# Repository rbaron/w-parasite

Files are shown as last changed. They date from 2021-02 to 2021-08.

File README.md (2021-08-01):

🚨 **This project is no longer recommended!** 🚨. Please check out the evolution of it - the [b-parasite](https://github.com/rbaron/b-parasite).

# w-parasite

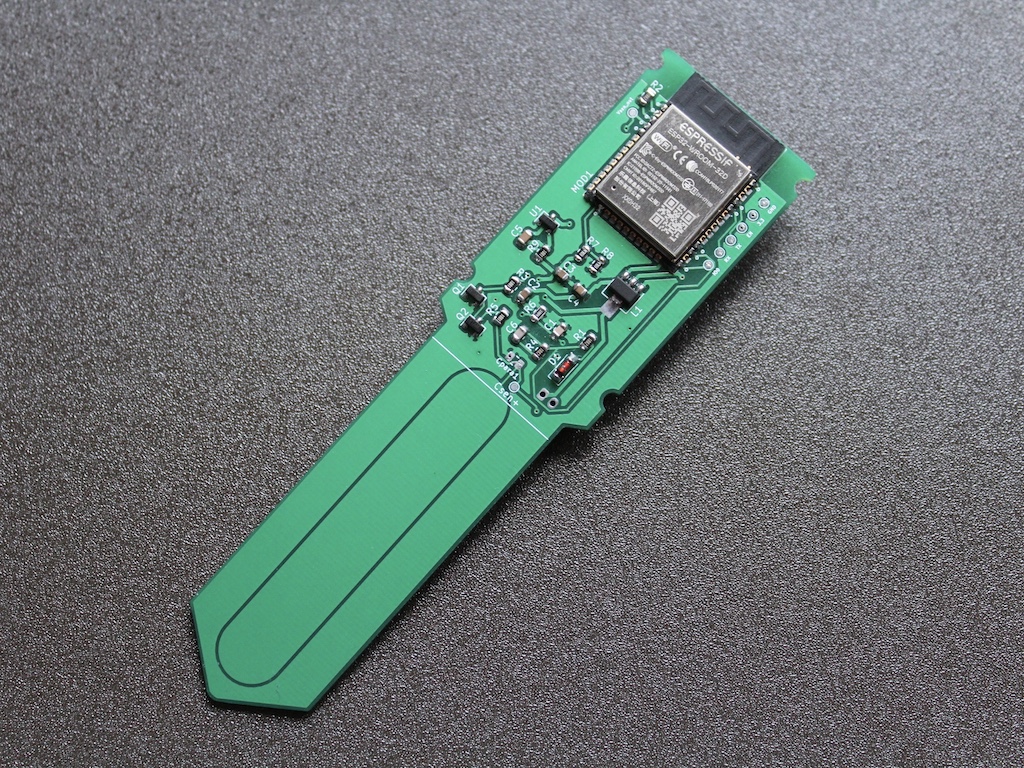
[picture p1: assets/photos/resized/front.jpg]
Front

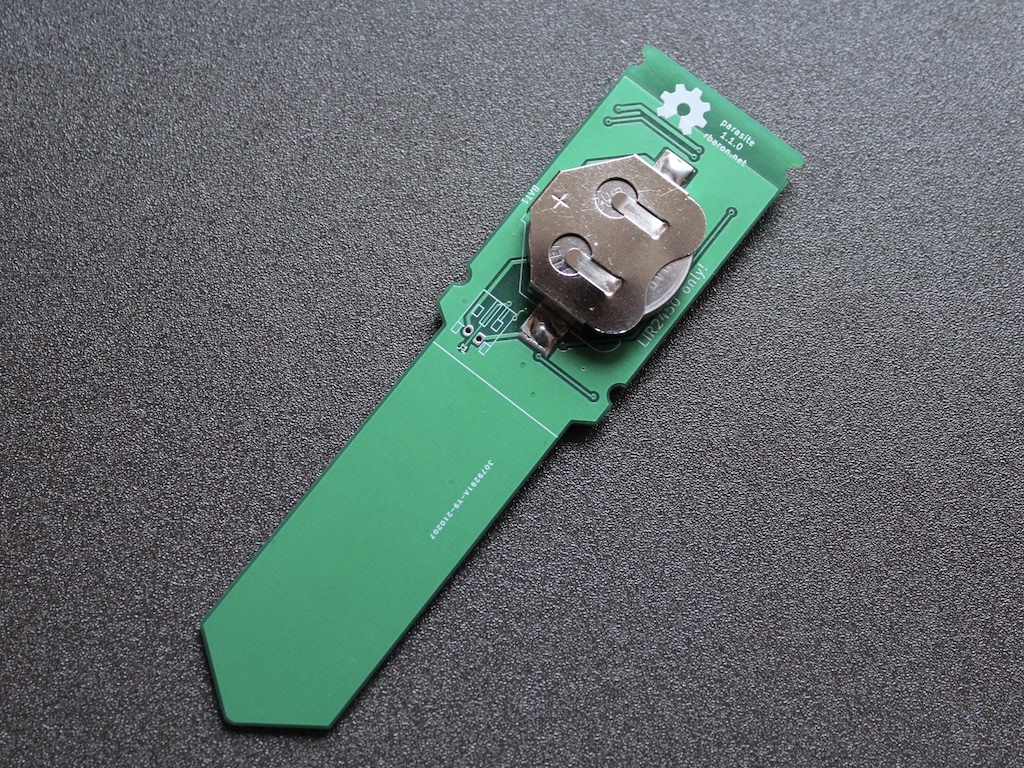
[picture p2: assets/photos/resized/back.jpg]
Back


w-parasite is an open source, WiFi-enabled soil moisture sensor for house plants.

This repo contains all the hardware design files (schematic, printed circuit board layout) and code for customizing and making your own w-parasite.

# How It Works
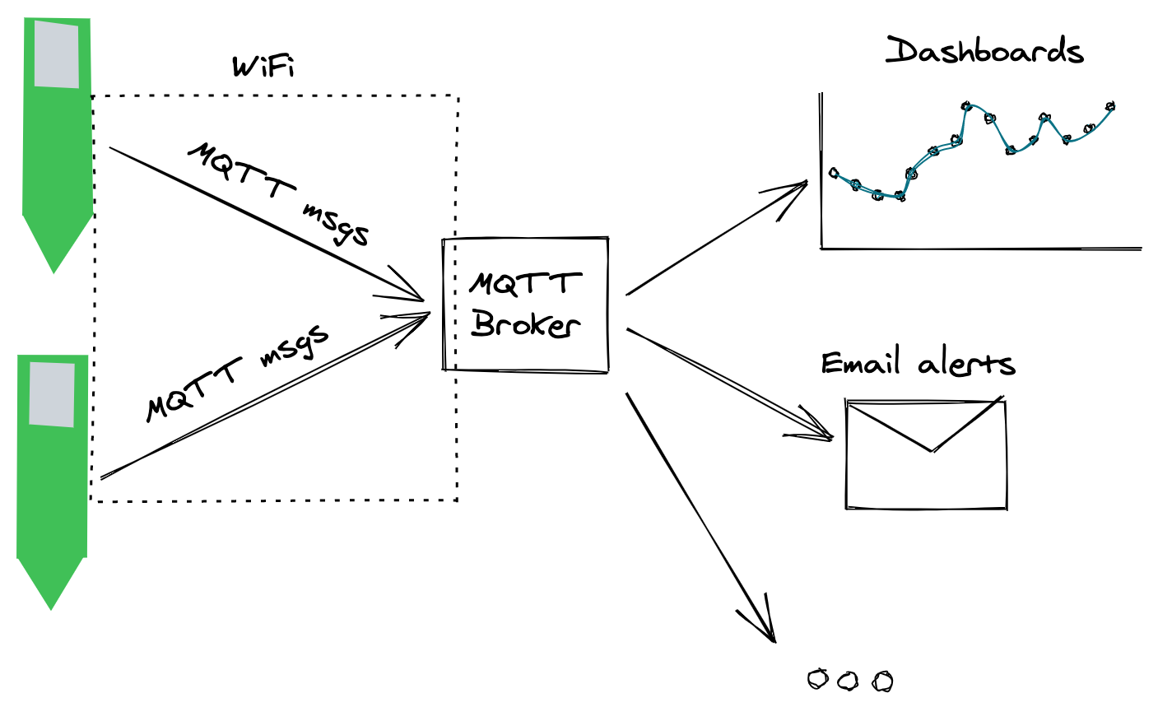
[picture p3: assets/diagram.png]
Diagram


w-parasite works by reading the soil moisture level and transmitting that information via MQTT messages via WiFi. To save battery, the board sleeps most of the time, and only wakes up every few minutes, at which point it takes a reading and ships it to the MQTT broker.

An [ESP32](https://www.espressif.com/en/products/socs/esp32) sits at the heart of the board, and is responsible for managing the sensors and connecting to WiFi.

The board can be powered with LiPo/Li-Ion batteries. There is a battery clip for rechargeable LIR2450 batteries, as well as a possibility for soldering a JST connector for beefier LiPo/Li-Ion batteries.

# Moisture Sensor
To measure the soil moisture, two PCB traces act like a disguised capacitor. These are the two large copper traces on the bottom of the board, on the part that goes into the soil. The capacitance between these two traces vary according to the amount of water around them, and we exploit that phenomenom to infer the soil moisture.

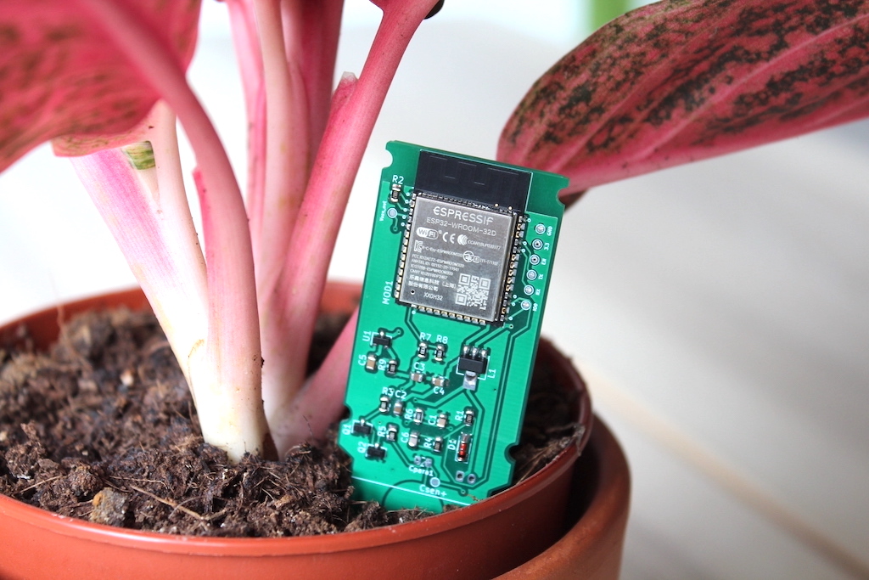
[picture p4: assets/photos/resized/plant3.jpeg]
A picture of the sensor in the ground


[This great post](https://wemakethings.net/2012/09/26/capacitance_measurement/) on wemakethings goes into detail about the inner workings of capacitive soil moisture sensors. I also expanded a little bit on the topic it in [here](https://twitter.com/rbaron_/status/1367182806368071685).

# Repo Organization
* [`code/`](./code/): Software. It's an [arduino-esp32](https://github.com/espressif/arduino-esp32/) [PlatformIO](https://platformio.org/) project;
* [`kicad/`](./kicad/): Hardware. It's a [KiCad](https://kicad.org/) project with the electronics schematic, PCB layout & fabrication files;

# Battery Life
To estimate the battery life and discuss our choices, we can agree on a few premisses:
1. Soil moisture doesn't change abruptly (except when watered). It is okay to wait several minutes between readings.
2. Most of the time, the sensor will be in a low power mode ("deep sleep"), in which its CPU is not active and it's not connected to WiFi. The current consumption in this state can be brought to around 15uA (10uA for the ESP32 and around 6uA for the voltage regulator - LDO);
3. When the sensor is active, its current consumption is orders of magniture higher. WiFi and ESP32 are not usually a good choice for low power devices, but since we can get away with such long periods of deep sleep, we might just barely get away with it. When active, w-parasite can consume peaks of over 200mA. It is paramount that we keep the active time short - cutting it down from 2 seconds to 1 second essentially doubles the battery life.

I have experimented with two main types of battery:
- LIR2450 Li-Ion coin cells. They are super compact (as in the photo above). With around 120mAh, they can only source short peaks of 200mA, which is below what the ESP32 expects. Using them poses a challenge on capacity and current, and that's why we like it so much;
- LiPo/Li-Ion cells. They are generally a lot bigger but usually pack up to 3000mAh. They take a lot of space but comfortably powers w-parasite for well over a year;

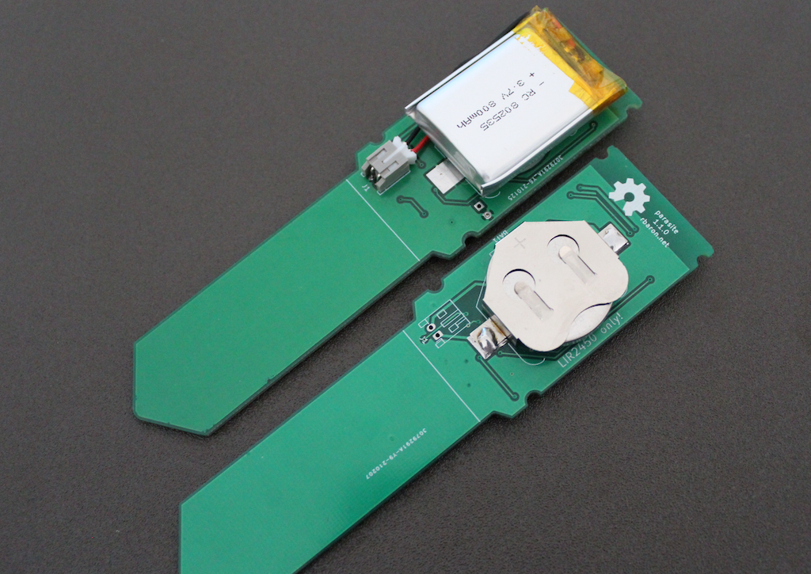
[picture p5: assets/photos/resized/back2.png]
Back with two w-parasites with different batteries


I put together [this spreadsheet](https://docs.google.com/spreadsheets/d/1Lt3Obveo7YzpxWigAVeM2rHjrGED6iG8pZ1Y3q1cldg/edit#gid=0) to estimate battery life. Here are some example scenarios:
- LIR2450 cell (120mAh), transmitting every 30 minutes: around 80-90 days.
- 1200mAh LiPo, transmitting every 10 minutes: over a year;
- 18650 Li-Ion (e.g.: 2700mAh), transmitting every 5 minutes: over a year;

# Possible Improvements
Ideas for improvements go in the direction of battery saving by shaving off precious milliseconds during the active cycle:

* Use a static IP address, BSSID and static dns servers. This has the downside of being less plug-and-play, so we need to investigate if the savings in connection time are worth it;
* Reduce boot time. We can configure esp-idf to suppress boot logging. This will probably require re-compiling the SDK ourselves, as Arduino/PlatformIO uses a prebuilt binary. See [this Github doc](https://github.com/espressif/arduino-esp32/blob/master/docs/esp-idf_component.md). [This Reddit thread](https://www.reddit.com/r/esp32/comments/fnj51a/a_guide_to_improving_esp32_boot_speed/) also has valuable info. Major savings seem to come from:
  * Pulling GPIO15 down on reset. It disables UART output;
  * Set BOOTLOADER_LOG_LEVEL to NONE/ERRORS;
  * ESPTOOL_FLASHMODE: QIO if possible;
  * SPIRAM_MEMTEST: disable RAM test;
* Experiment with a 3.0V LDO (such as the HT7330). The ESP32 should be able to run with 3.0V (instead of the nominal 3.3V we're using here, which has a 0.9V dropout voltage, so we can only power it with at least 3.39V). This would make better use of the LIR2450 cell. From the [LIR2450 discharge curve](https://devzone.nordicsemi.com/cfs-file/__key/communityserver-discussions-components-files/4/1307.3.png), I don't think the gains are massive, but we could probably squeeze 10%-ish more out of the LIR2450;
* Tigther MQTT messages. We currently send out multiple MQTT messages. This makes it easy to work with on the other end, but we can probably do better to bring the runtime down;

# Why not Bluetooth Low Energy (BLE)?
Excellent question! With BLE, we can work with much lower currents, and we can power the board with even cheaper batteries like the ubiquitous CR2032. SoCs like the [nRF5](https://www.nordicsemi.com/Products/Low-power-short-range-wireless) family from Nordic are much better suited for ultra low power applications. They idle at less than 1uA and can transmit with ~5mA (compare with 100-200mA for the ESP32 + WiFi)! I believe they are a better fit for battery-powered, intermittent sensors like this one. Moreover, ESP32, _specially_ with WiFi is notoriously power hungry. Even if we implement all the tricks in the book, we won't likely match the power efficiency of BLE-only chips.

With all that out of the way, if we power this with a beefier LiPo/Li-Ion battery, we can hopefuly already run for over a year on a single charge, with the added advantage of having a simpler architechure and more friendly - the sensor talks directly to your MQTT broker. Additionally, BLE devices usually have a much lower range and often require bridges for integrating with the rest of our system.

# News & Updates
For the freshest w-parasite updates, follow [@rbaron_](https://twitter.com/rbaron_).

# License
The hardware and associated design files are released under the [Creative Commons CC BY-SA 4.0 license](https://creativecommons.org/licenses/by-sa/4.0/).
The code is released under the [MIT license](https://opensource.org/licenses/MIT).

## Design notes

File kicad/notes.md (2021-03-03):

# LIR2450 Coin Battery
- Capacity ~130 mAh
- Charging current ~45mA (0.5C)

Available chargers are suspiciously cheap and rare.

## ICS for charging
- [LTC4071](https://www.analog.com/media/en/technical-documentation/data-sheets/LTC4071.pdf)
- [MCP73831/2](https://cdn-reichelt.de/documents/datenblatt/A200/MCP73831-2_ENG_TDS.pdf)
  Seems easier to use, but does not offer undervoltage protection.
- [MCP73831]

## ICS for protection against undercharge/overcurrent
- [DW01A](https://lcsc.com/product-detail/Battery-Protection-ICs_PUOLOP-DW01A_C351410.html)
  This one I found built-in into protected batteries, but it requires two external MOSFETS.
- [XB6566H](https://datasheet.lcsc.com/szlcsc/1810010232_XySemi-XB6566H0_C190847.pdf)
  Used on the esp32 coin project. Requires minimal external components.

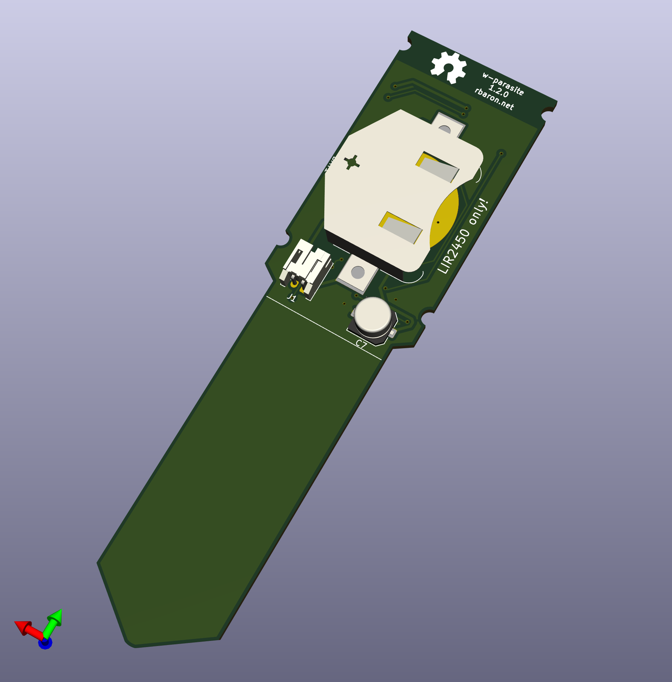
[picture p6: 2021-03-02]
assets/3dback.png

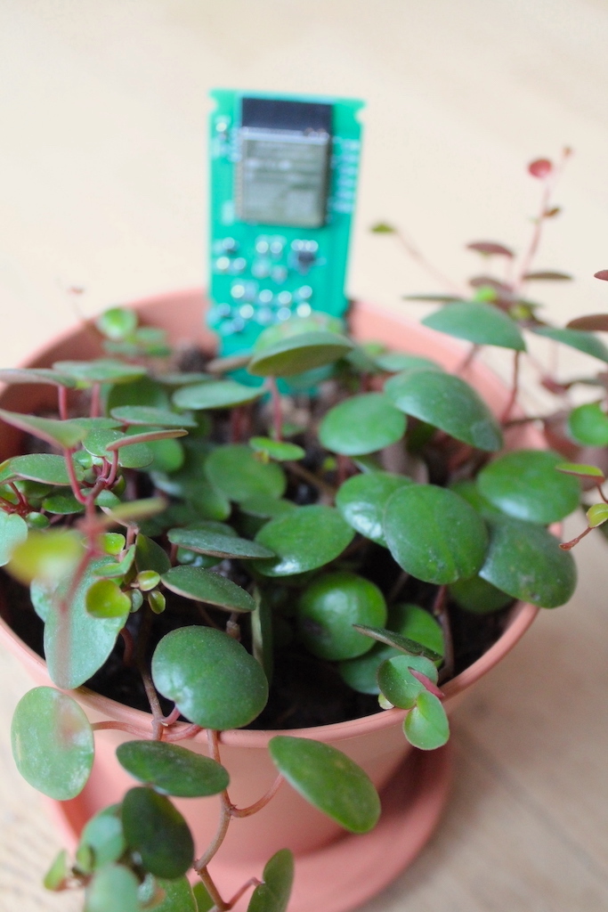
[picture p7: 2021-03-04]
assets/photos/resized/plant1.jpg

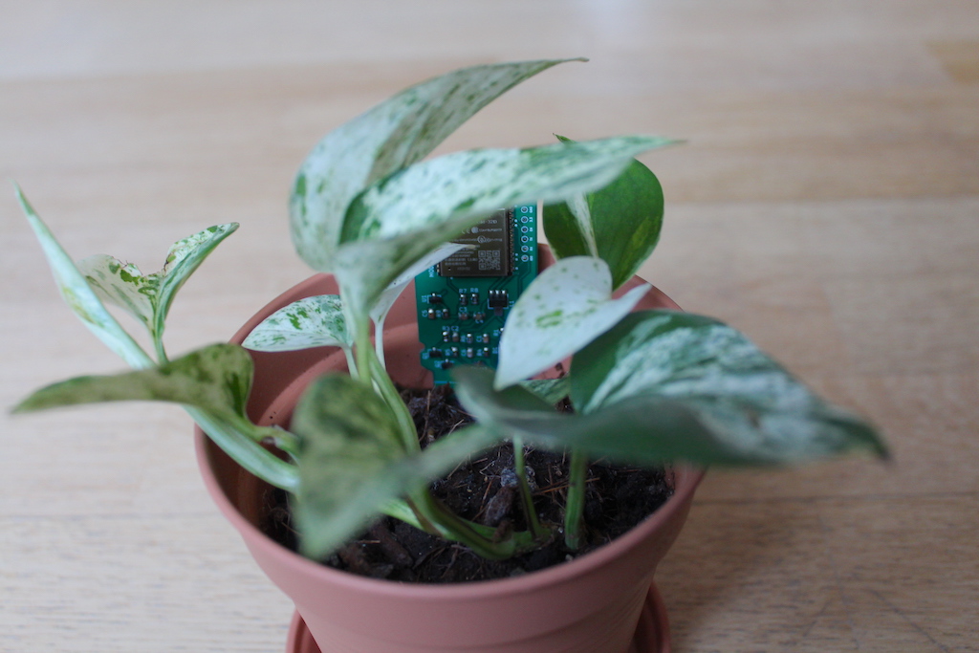
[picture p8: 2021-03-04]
assets/photos/resized/plant2.jpg

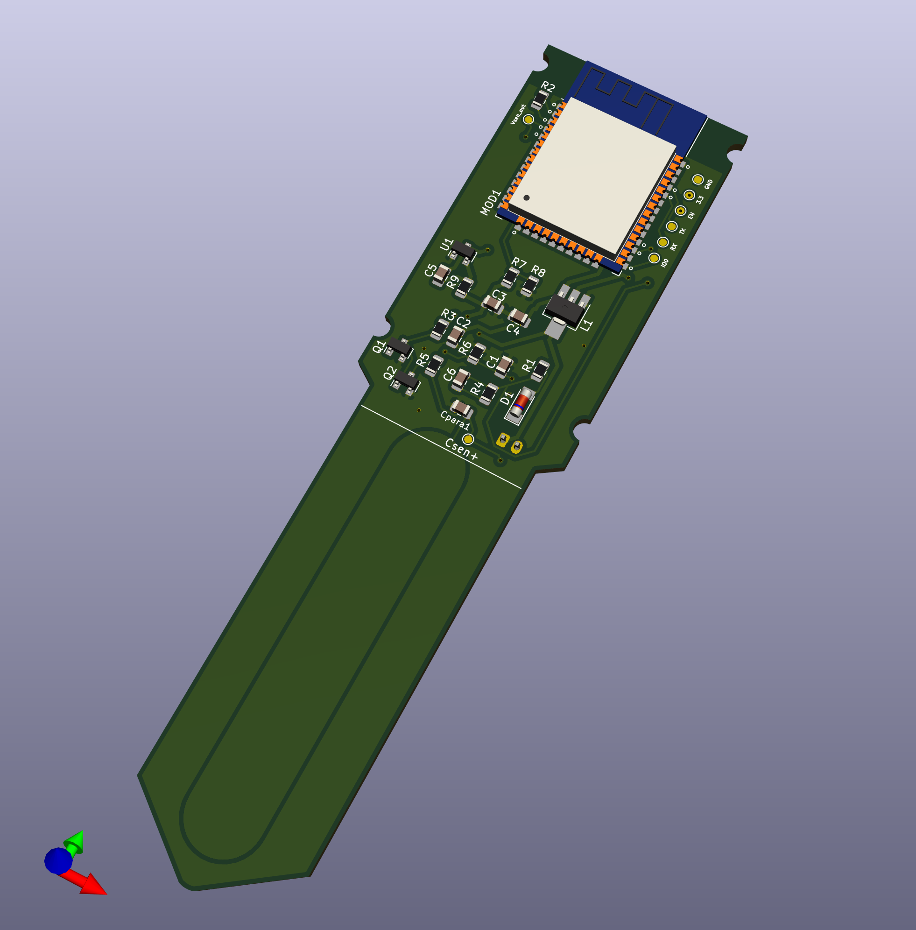
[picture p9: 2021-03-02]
assets/3dfront.png

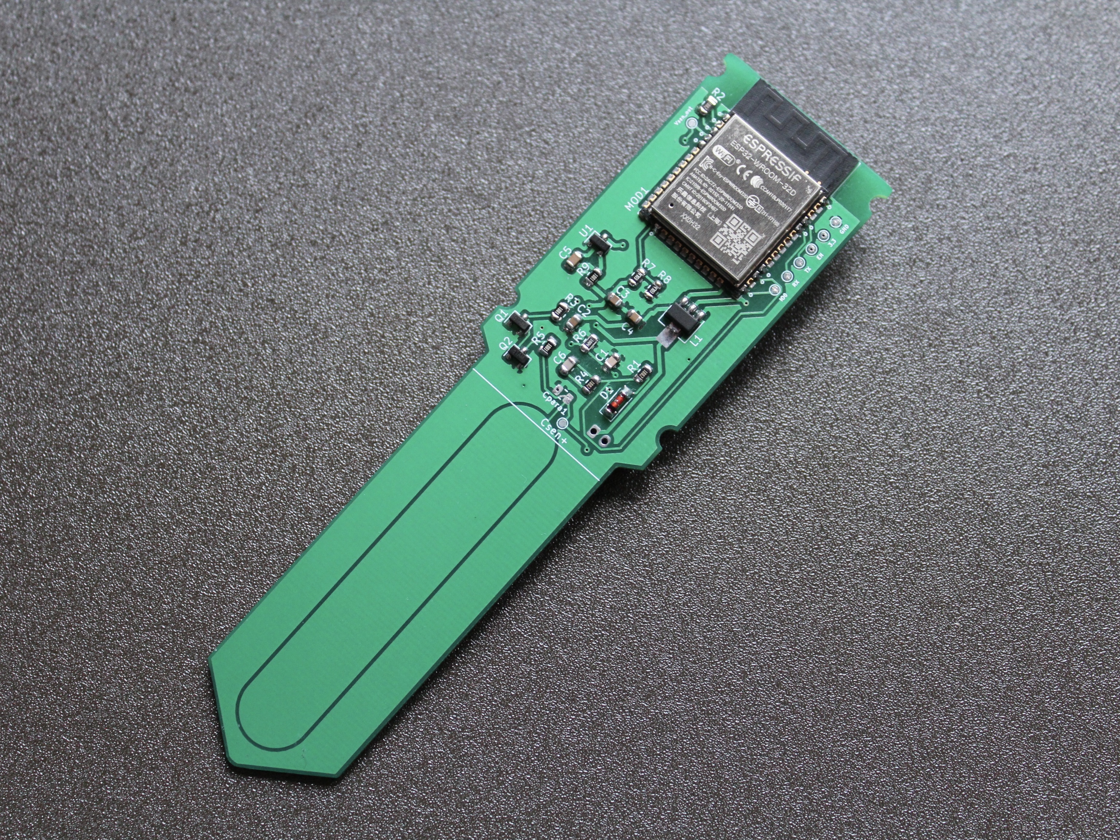
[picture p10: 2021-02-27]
assets/photos/original/front.jpg

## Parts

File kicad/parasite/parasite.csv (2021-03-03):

Id | Designator | Package | Quantity | Designation | Supplier and ref
1 | G*** | OSHW-logo_silkscreen-back_8mm | 1 | OSHW-logo_silkscreen-back_8mm
2 | BAT1 | BatteryHolder_Keystone_3008_1x2450 | 1 | BS-7
3 | R8,R7 | R_0805_2012Metric | 2 | 470k
4 | TP9 | TestPoint_Pad_D1.0mm | 1 | GND
5 | TP8 | TestPoint_Pad_D1.0mm | 1 | 3.3
6 | Q2,Q1 | SOT-23 | 2 | MMBT3904
7 | Cpara1 | C_0805_2012Metric | 1 | 5p
8 | C1 | C_0805_2012Metric | 1 | 1n
9 | C2,C3,C4 | C_0805_2012Metric | 3 | 10u
10 | D1 | D_MiniMELF | 1 | LL4148
11 | J1 | JST_PH_S2B-PH-K_1x02_P2.00mm_Horizontal | 1 | Conn_01x02_Female
12 | L1 | SOT-89-3_Handsoldering | 1 | HT7333-A
13 | MOD1 | ESP32-WROOM-32 | 1 | ESP32-WROOM-32
14 | R1,R2,R4 | R_0805_2012Metric | 3 | 10k
15 | R3,R5,R9 | R_0805_2012Metric | 3 | 1k
16 | R6 | R_0805_2012Metric | 1 | 1M
17 | TP1 | TestPoint_Pad_D1.0mm | 1 | IO0
18 | TP2 | TestPoint_Pad_D1.0mm | 1 | EN
19 | TP3 | TestPoint_Pad_D1.0mm | 1 | Csen+
20 | TP4 | TestPoint_Pad_D1.0mm | 1 | Vsen_out
21 | TP5 | TestPoint_Pad_D1.0mm | 1 | TX
22 | TP6 | TestPoint_Pad_D1.0mm | 1 | RX
23 | C6 | C_0805_2012Metric | 1 | 100p
24 | C5 | C_0805_2012Metric | 1 | 0.1u
25 | U1 | SOT-23 | 1 | XB3303A

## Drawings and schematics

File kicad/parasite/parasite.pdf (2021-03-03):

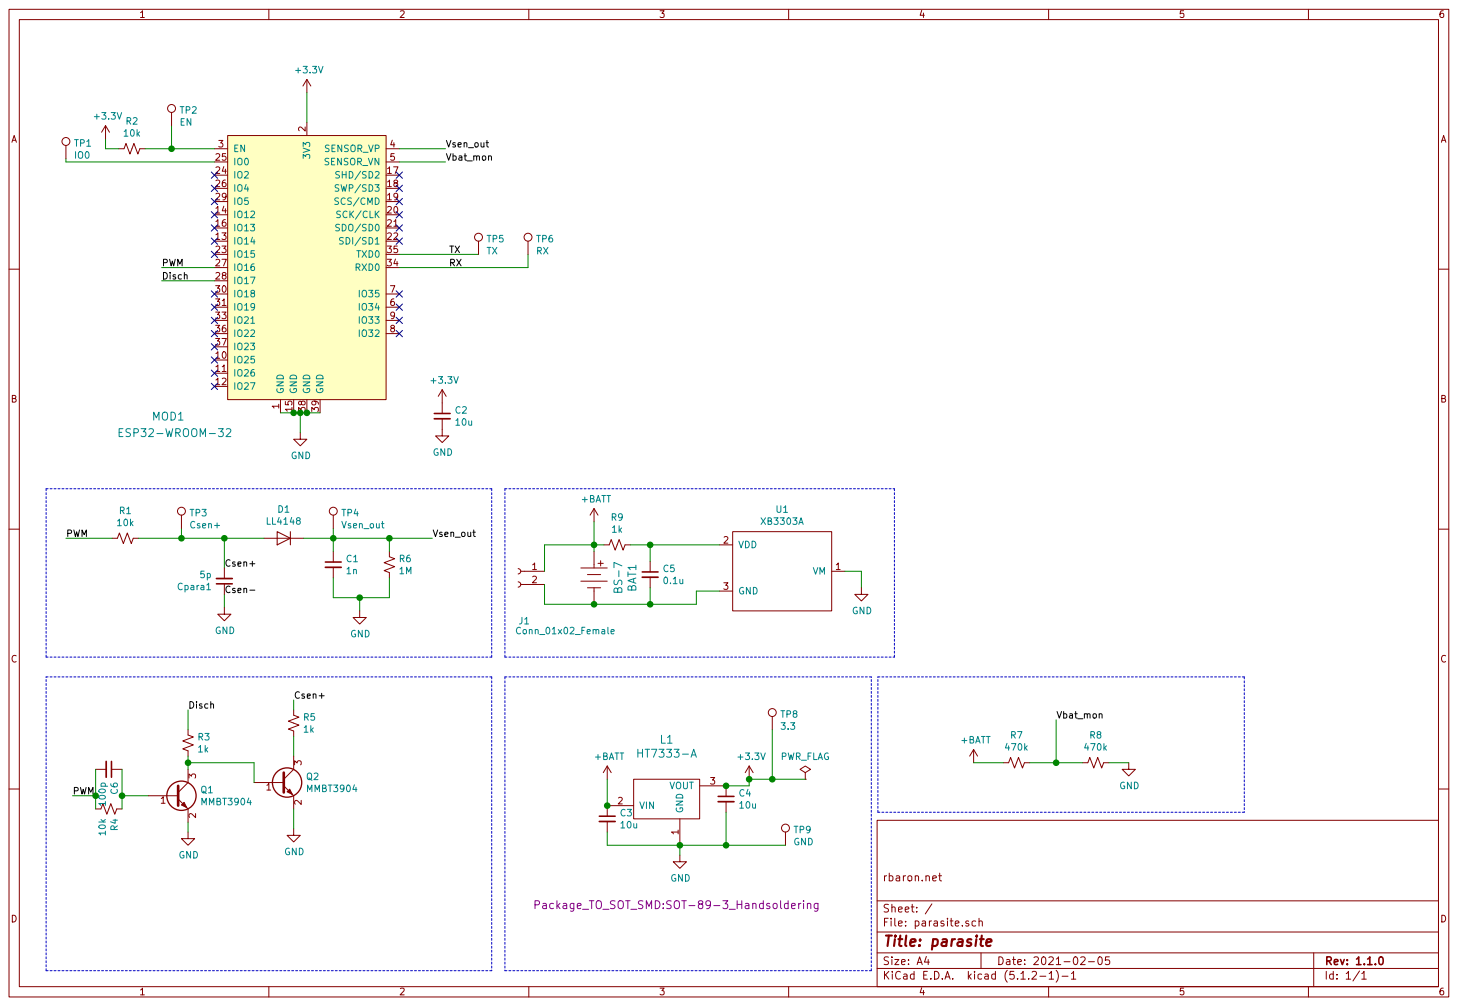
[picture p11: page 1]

File: parasite.sch Sheet: / rbaron.net GND

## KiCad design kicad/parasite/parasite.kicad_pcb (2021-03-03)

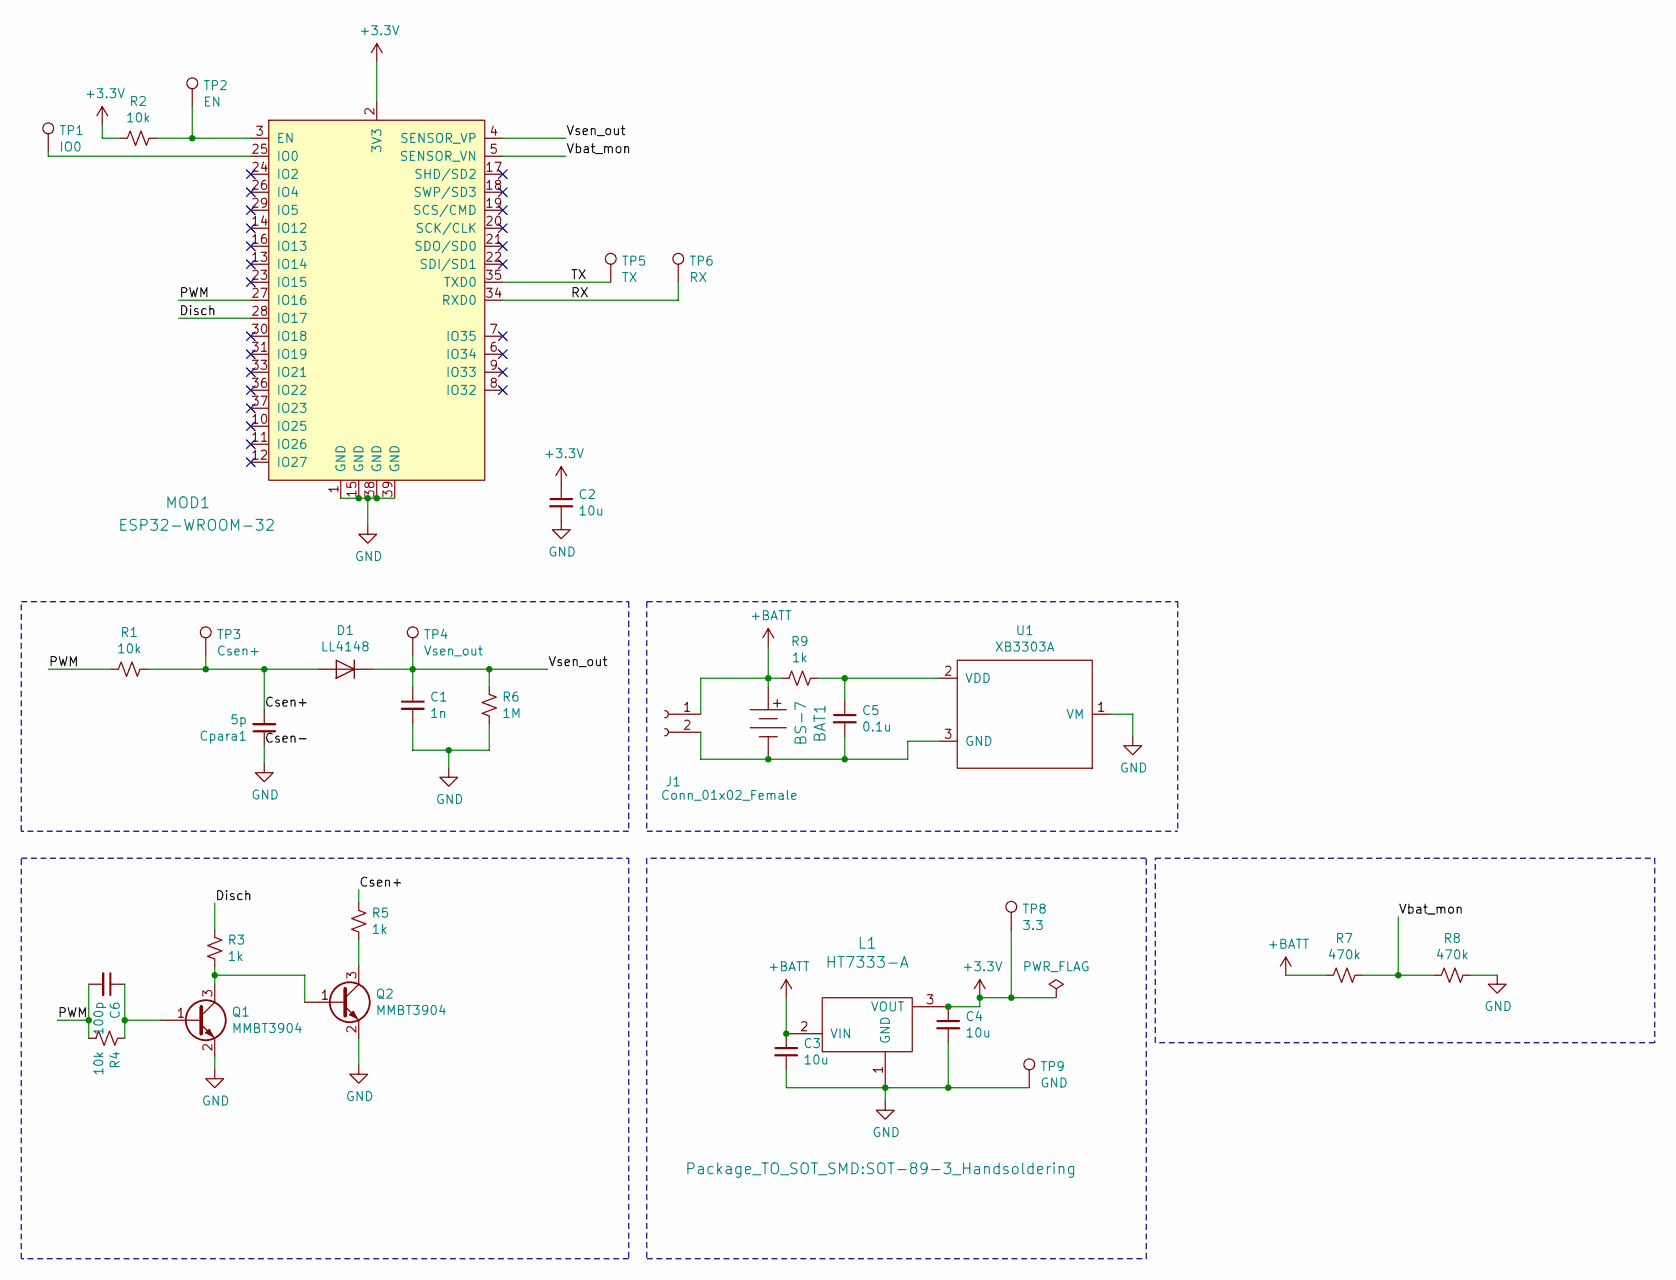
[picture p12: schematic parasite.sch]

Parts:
BAT1: BS-7; BatteryHolder_Keystone_3008_1x2450; MPN BS-7; Digi-Key_PN BS-7-ND
C1: 1n; C_0805_2012Metric
C2, C3, C4: 10u; C_0805_2012Metric
C5: 0.1u; C_0805_2012Metric
C6: 100p; C_0805_2012Metric
Cpara1: 5p; C_0805_2012Metric
D1: LL4148; D_MiniMELF
J1: Conn_01x02_Female; JST_PH_S2B-PH-K_1x02_P2.00mm_Horizontal
L1: HT7333-A; SOT-89-3_Handsoldering
MOD1: ESP32-WROOM-32; MPN ESP32-WROOM-32; Digi-Key_PN 1904-1010-1-ND
Q1, Q2: MMBT3904; SOT-23
R1, R2, R4: 10k; R_0805_2012Metric
R3, R5, R9: 1k; R_0805_2012Metric
R6: 1M; R_0805_2012Metric
R7, R8: 470k; R_0805_2012Metric
TP1: IO0; TestPoint_Pad_D1.0mm
TP2: EN; TestPoint_Pad_D1.0mm
TP3: Csen+; TestPoint_Pad_D1.0mm
TP4: Vsen_out; TestPoint_Pad_D1.0mm
TP5: TX; TestPoint_Pad_D1.0mm
TP6: RX; TestPoint_Pad_D1.0mm
TP8: 3.3; TestPoint_Pad_D1.0mm
TP9: GND; TestPoint_Pad_D1.0mm
U1: XB3303A; SOT-23

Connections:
+3V3: C2.1, C4.1, L1.3 (VOUT), MOD1.2 (3V3), R2.1, TP8.1
+BATT: BAT1.Pos, C3.1, J1.1, L1.2 (VIN), R7.1, R9.1
/Csen+: Cpara1.2, D1.2 (A), R1.2, R5.1, TP3.1
/Disch: MOD1.28 (IO17), R3.1
/PWM: C6.2, MOD1.27 (IO16), R1.1, R4.2
/RX: MOD1.34 (RXD0), TP6.1
/TX: MOD1.35 (TXD0), TP5.1
/Vbat_mon: MOD1.5 (SENSOR_VN), R7.2, R8.1
/Vsen_out: C1.1, D1.1 (K), MOD1.4 (SENSOR_VP), R6.1, TP4.1
GND: C1.2, C2.2, C3.2, C4.2, Cpara1.1, L1.1 (GND), MOD1.1 (GND), MOD1.15 (GND), MOD1.38 (GND), MOD1.39 (GND), Q1.2 (E), Q2.2 (E), R6.2, R8.2, TP9.1, U1.1 (VM)
unnamed: BAT1.Neg, C5.2, J1.2, U1.3 (GND)
unnamed: C5.1, R9.2, U1.2 (VDD)
unnamed: C6.1, Q1.1 (B), R4.1
unnamed: MOD1.3 (EN), R2.2, TP2.1
unnamed: MOD1.25 (IO0), TP1.1
unnamed: Q1.3 (C), Q2.1 (B), R3.2
unnamed: Q2.3 (C), R5.2

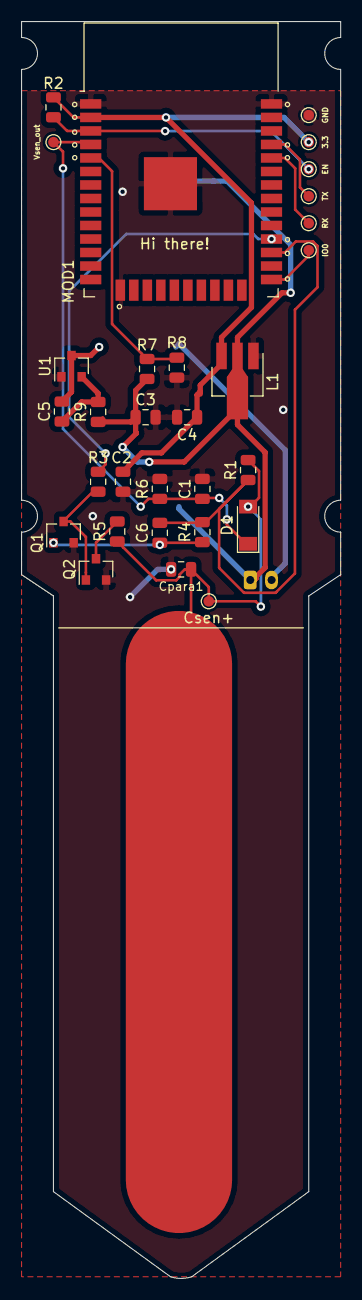
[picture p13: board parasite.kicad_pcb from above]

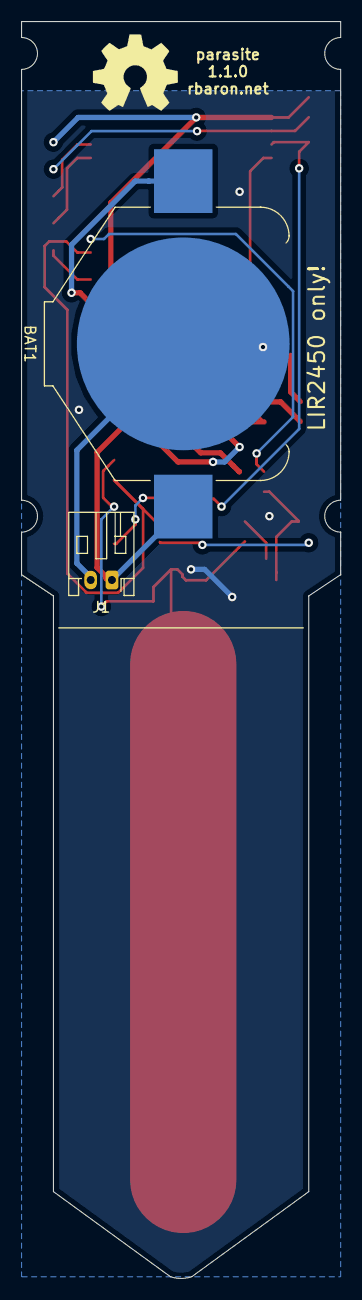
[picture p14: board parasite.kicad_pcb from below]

Board: 2 copper layers, 30.0 x 118.2 mm, 32 parts (2 on the bottom side), 17 nets.

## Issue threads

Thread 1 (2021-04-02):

Brownout detector was triggered when powering of CR2450

sillevl, 2021-04-02:
When powering the circuit from a CR2450 battery, I only get brownout's and the code never starts...

```
ets Jun  8 2016 00:22:57

rst:0xc (SW_CPU_RESET),boot:0x13 (SPI_FAST_FLASH_BOOT)
configsip: 0, SPIWP:0xee
clk_drv:0x00,q_drv:0x00,d_drv:0x00,cs0_drv:0x00,hd_drv:0x00,wp_drv:0x00
mode:DIO, clock div:2
load:0x3fff0018,len:4
load:0x3fff001c,len:1044
load:0x40078000,len:10124
load:0x40080400,len:5828
entry 0x400806a8

Brownout detector was triggered
```

I would have expected this behaviour as the ESP requires a large current at startup and wifi communication. How did you solve this problem? I see pictures from you using an CR2450 battery.

rbaron, 2021-04-04:
Hey there. I use a LIR2450 Li-Ion battery here, but I had a similar problem. On occasion, the brownout detector was tripping me up.

I think a proper solution (short of using a beefier LiPo/Li-Ion battery) would be to stick a really big capacitor across the power lines, but that comes at comes at a cost (charging up the cap, self discharge). I unfortunately had to disable the brownout detector (done [here](https://github.com/rbaron/w-parasite/blob/main/code/src/main.cpp#L35), with a heartfelt comment). I really dislike having to do this, and I am both happy and disappointed that it works.

The bottomline for me is that it is super tricky to get the ESP32 to run well on tiny batteries. I moved the design to use BLE and a nRF52 chip in [rbaron/b-parasite](https://github.com/rbaron/b-parasite).

sillevl, 2021-04-05:
@rbaron thanks for the feedback. I have tested it with LIR2450 cells as wel, but after 2 hours it just dies. Might be an old cell. I ordered some new ones to be sure.
I knew ESP's and coin cells are a real challenge. I just hoped you figured it out :)
I might try to build a sensor using LoRaWAN and an STM32L4 microcontroller. I have build some low power devices using that configuration in the past.

Closed 2021-04-05.

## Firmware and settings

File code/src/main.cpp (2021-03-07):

#include <Arduino.h>
#include <driver/adc.h>
#include <esp_attr.h>
#include <soc/rtc_cntl_reg.h>
#include <soc/soc.h>

#include "parasite/batt.h"
#include "parasite/config.h"
#include "parasite/mqtt_client.h"
#include "parasite/pwm.h"
#include "parasite/soil_moisture.h"
#include "parasite/wifi.h"

constexpr int kSToUSFactor = 1000000;

// RTC_DATA_ATTR makes these data persistent across deep-sleep cycles.
RTC_DATA_ATTR unsigned int boot_count = 0;
RTC_DATA_ATTR unsigned int clean_exit_count = 0;

unsigned long t0 = millis();

void run() {
  // I'm fighting through tears as I painfully disable the brownout detector.
  // To keep things low power, I'm using a small LDO (HT7333) that has ~8uA
  // quiescent current, but can source only up to 250mA peak current.
  // Additionally, the LIR2450 can only handle 200mA peak current. These
  // restrictions on current are below what the ESP32 requires (up to 500mA!),
  // and sometimes it trigger the brownout detector, specially right when
  // connecting to WiFi. Disabling the brownout detector is a bad idea in
  // general (and here included, as it can lead to weird and hard to debug
  // failure modes, not to mention undefined behavior), but in my tests it seems
  // like we can work through it, and the system behaves as expected. As we try
  // to squeeze every Coulomb of useful charge from our tiny battery, this abuse
  // seems to be the price to pay.
  WRITE_PERI_REG(RTC_CNTL_BROWN_OUT_REG, 0);

  parasite::pwm::StartPWM();
  parasite::soil_moisture::soil_moisture_read_t moisture =
      parasite::soil_moisture::ReadSoilMoisture();
  Serial.printf("Read moisture: %d -> %f\n", moisture.raw, moisture.percentage);
  parasite::pwm::StopPWM();

  parasite::batt::batt_read_t batt = parasite::batt::ReadBattVoltage();
  Serial.printf("Read batt: %f -> %f\n", batt.raw, batt.voltage);

  if (parasite::wifi::SetupWiFi(&Serial) != WL_CONNECTED) {
    Serial.println("Giving up connecting to WiFi for now.");
    return;
  }

  parasite::mqtt::MQTTClient mqtt_client(&Serial);

  if (!mqtt_client.Loop()) {
    Serial.println("Error calling mqtt_client.Loop(). Giving up.");
    return;
  }

  mqtt_client.Publish(PRST_MQTT_TOPIC_SOIL_MOISTURE_PERCENT,
                      moisture.percentage, true);
  mqtt_client.Publish(PRST_MQTT_TOPIC_BATT_VOLTAGE, batt.voltage, true);
  mqtt_client.Publish(PRST_MQTT_TOPIC_SOIL_MOISTURE_RAW, moisture.raw, true);
  mqtt_client.Publish(PRST_MQTT_TOPIC_BATT_VOLTAGE_RAW, batt.raw, true);
  mqtt_client.Publish(PRST_MQTT_TOPIC_RUNTIME, millis() - t0, true);
  mqtt_client.Publish(PRST_MQTT_TOPIC_BOOT_COUNT, boot_count, true);
  mqtt_client.Publish(PRST_MQTT_TOPIC_CLEAN_EXIT_COUNT, clean_exit_count, true);
  mqtt_client.Publish(PRST_MQTT_TOPIC_ERROR_COUNT,
                      boot_count - clean_exit_count - 1, true);

  mqtt_client.FlushAndDisconnect();

  // This shouldn't be necessary, but apparently we're missing some published
  // messages.
  delay(50);

  parasite::wifi::DisconnectWiFi();
  clean_exit_count++;
}

void setup() {
  boot_count += 1;
  Serial.begin(115200);

  run();

  // Go to sleep.
  adc_power_off();
  esp_sleep_enable_timer_wakeup(PRST_DS_TIME_TO_SLEEP_IN_SECONDS *
                                kSToUSFactor);
  esp_deep_sleep_start();
}

void loop() {}

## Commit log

2021-03-03 Moved kicad/ project here from my homeauto monorepo
    [parasite-B_Cu.gbr, parasite-B_Mask.gbr, parasite-B_Paste.gbr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]
2021-03-03 Plots schematic PDF
2021-03-13 Adds experiments/touch_sensor
    In this experiment we use a capacitive touch sensor pin to estimate
    the soil moisture without any external circuits.
